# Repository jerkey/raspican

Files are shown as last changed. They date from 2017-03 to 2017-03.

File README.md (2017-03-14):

# raspican
##raspberry pi CANbus hardware in kicad
schematic
board
README.md for raspican Hardware
Files .pro .sch and .kicad_pcb in KiCAD format
License CC BY-SA 3.0
raspican Hardware

how to setup cansend software on the raspberry pi:
-------------------------------------------------
http://skpang.co.uk/blog/archives/1165

_Inspired by retired PICAN project at:_

http://skpang.co.uk/catalog/pican-canbus-board-retired-replacement-available-p-1196.html

````
22:54 < jerkey_> http://www.cowfishstudios.com/blog/canned-pi-part1
23:25 <@amatus> this stuff is out of date
23:25 <@amatus> this is what i did:
23:26 <@amatus> sudo apt-get install can-utils
23:26 <@amatus> echo dtoverlay=mcp2515-can0,oscillator=16000000,interrupt=25 >> /boot/config.txt
23:27 <@amatus> reboot
23:36 <@amatus> scratch that, echo dtoverlay=mcp2515-can0 >> /boot/config.txt
23:40 < jerkey_> https://github.com/jerkey/raspican
23:50 <@amatus> then follow the ip ... commands
Day changed to 14 Mar 2017
00:56 < jerkey_> i bet your car wasn't spitting rhymes where it was supposed to.  i can't find anything wrong with this hardware!
````

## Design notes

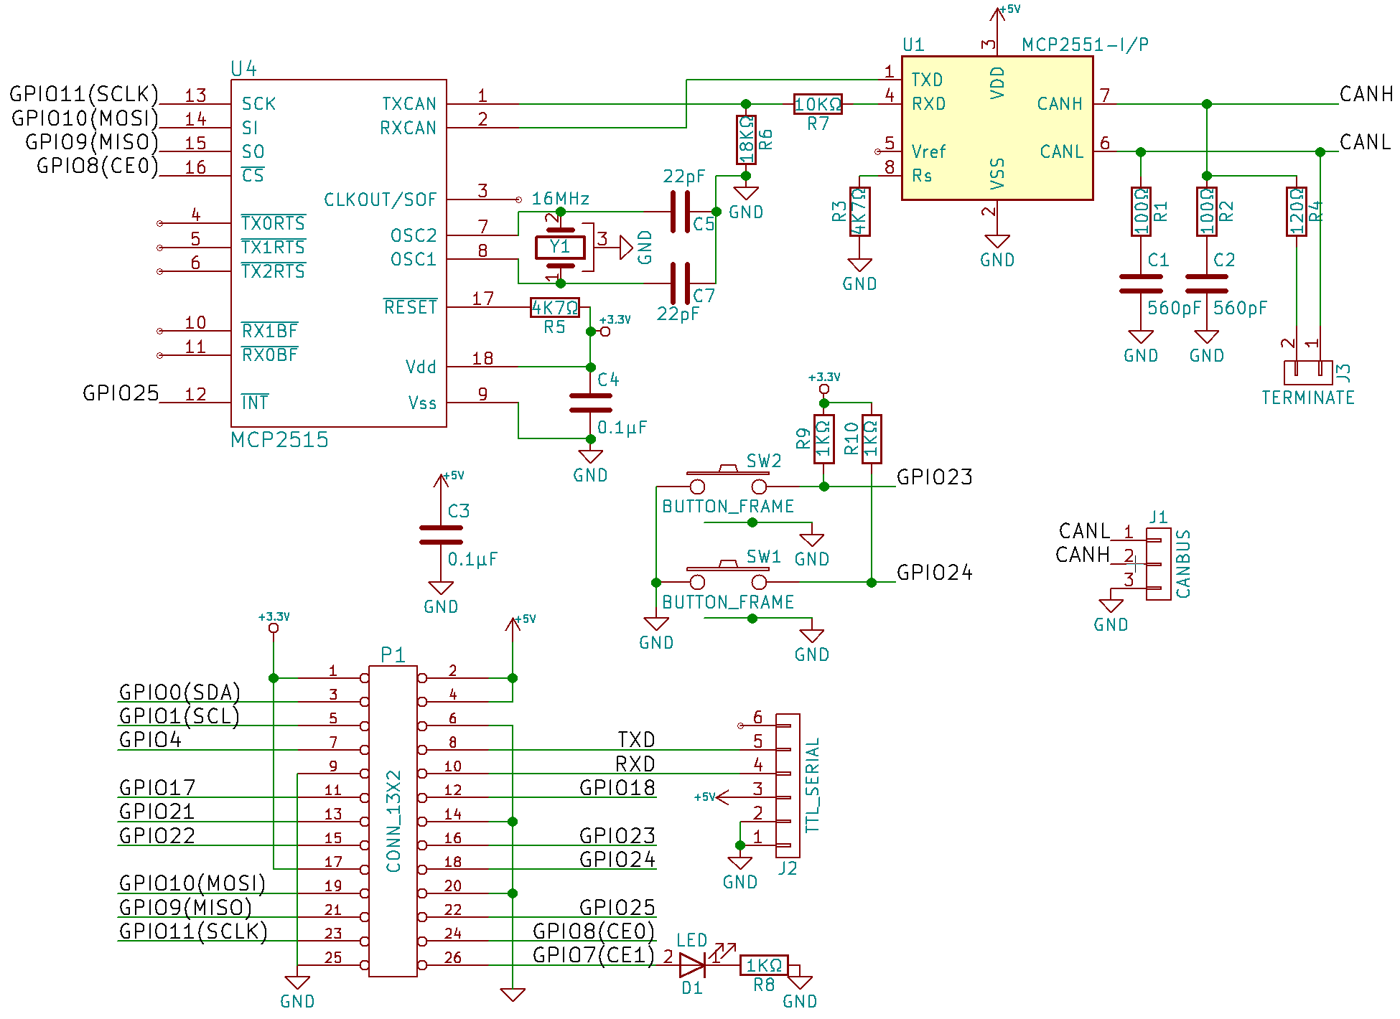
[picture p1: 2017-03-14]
schematic.png

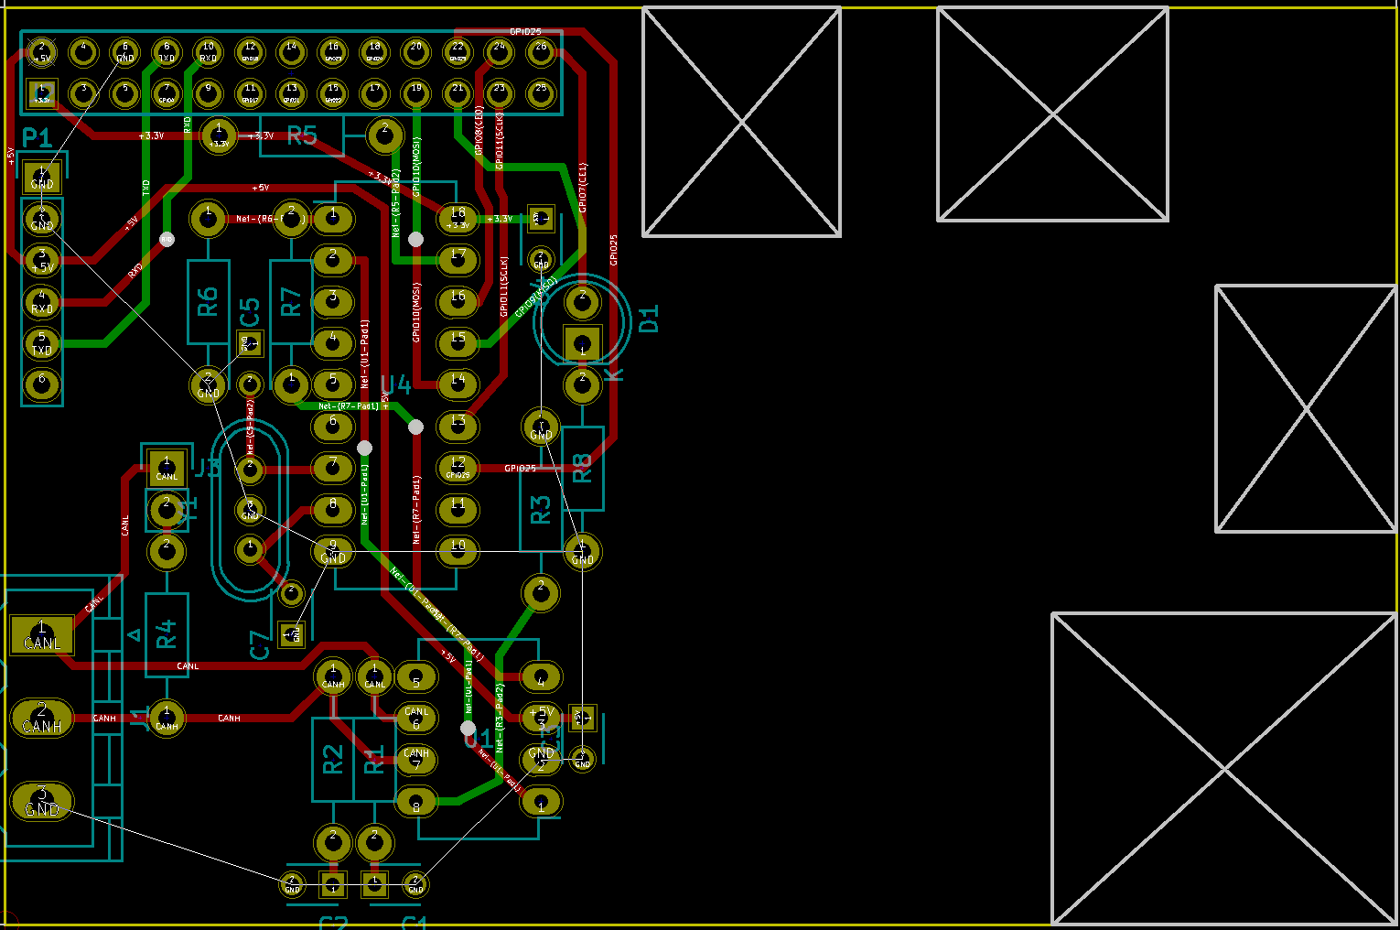
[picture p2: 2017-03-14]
board.png

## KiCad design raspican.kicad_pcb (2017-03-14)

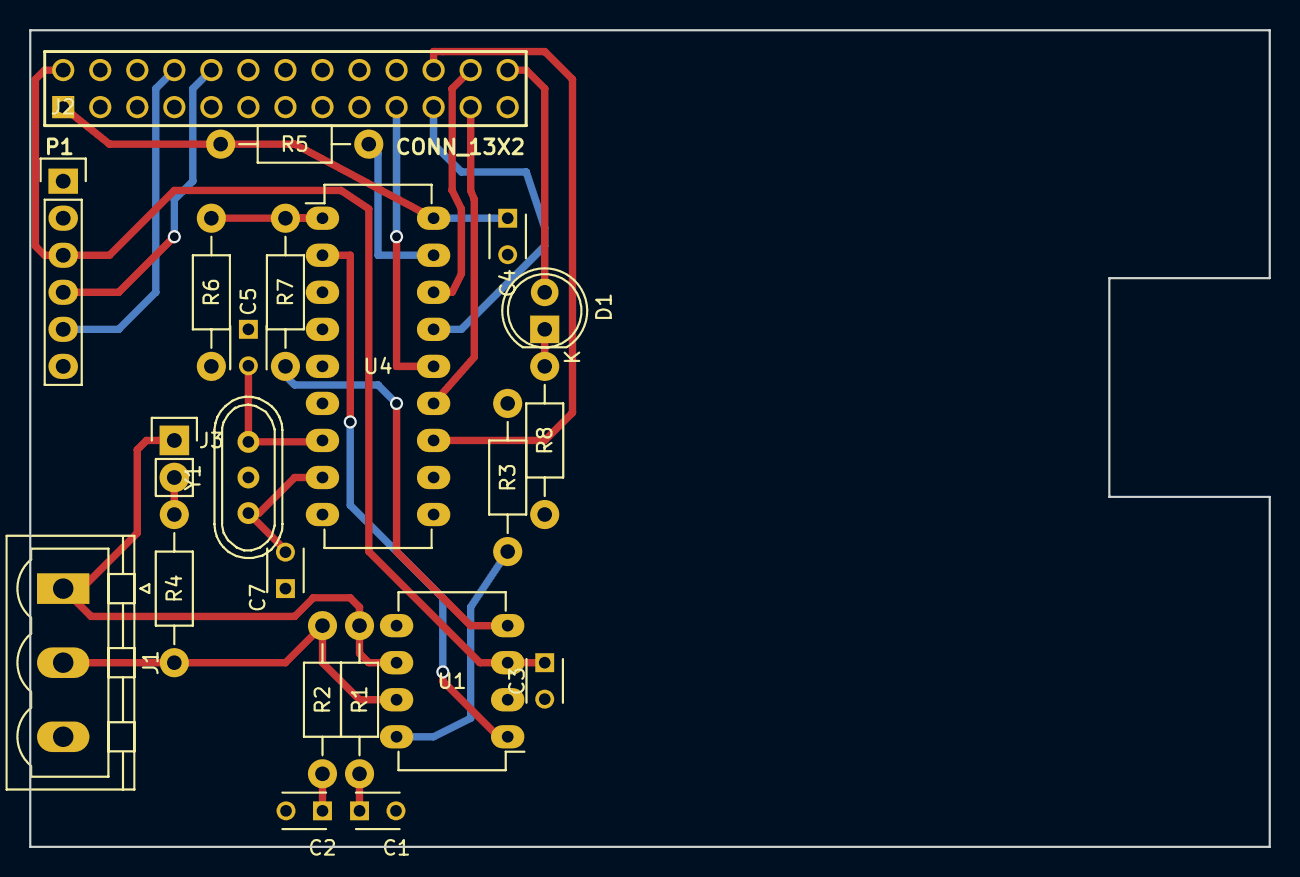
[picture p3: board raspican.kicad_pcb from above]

Board: 2 copper layers, 85.0 x 56.0 mm, 22 parts (0 on the bottom side), 24 nets.

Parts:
C1, C2: 560pF; C_Disc_D3_P2.5
C3, C4: 0.1μF; C_Disc_D3_P2.5
C5, C7: 22pF; C_Disc_D3_P2.5
D1: LED; LED-5MM
J1: CANBUS; PhoenixContact_MSTBVA-G_03x5.08mm_Vertical
J2: TTL_SERIAL; Pin_Header_Straight_1x06
J3: TERMINATE; Pin_Header_Straight_1x02
P1: CONN_13X2; pin_array_13x2
R1, R2: 100Ω; Resistor_Horizontal_RM10mm
R3, R5: 4K7Ω; Resistor_Horizontal_RM10mm
R4: 120Ω; Resistor_Horizontal_RM10mm
R6: 18KΩ; Resistor_Horizontal_RM10mm
R7: 10KΩ; Resistor_Horizontal_RM10mm
R8: 1KΩ; Resistor_Horizontal_RM10mm
U1: MCP2551-I/P; DIP-8_W7.62mm_LongPads
U4: MCP2515; DIP-18_W7.62mm_LongPads
Y1: 16MHz; Crystal_HC49-U_Vertical_3Pin

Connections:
+3.3V: C4.1, P1.1, R5.1, U4.18
+5V: C3.1, J2.3, P1.2, U1.3
/CANH: J1.2, R2.1, R4.1, U1.7
/CANL: J1.1, J3.1, R1.1, U1.6
/GPIO7(CE1): D1.2, P1.26
/GPIO8(CE0): P1.24, U4.16
/GPIO9(MISO): P1.21, U4.15
/GPIO10(MOSI): P1.19, U4.14
/GPIO11(SCLK): P1.23, U4.13
/GPIO25: P1.22, U4.12
/RXD: J2.4, P1.10
/TXD: J2.5, P1.8
GND: C1.2, C2.2, C3.2, C4.2, C5.1, C7.1, J1.3, J2.1, J2.2, P1.6, R3.1, R6.2, R8.1, U1.2, U4.9, Y1.3
unnamed: C1.1, R1.2
unnamed: C2.1, R2.2
unnamed: C5.2, U4.7, Y1.2
unnamed: C7.2, U4.8, Y1.1
unnamed: D1.1, R8.2
unnamed: J3.2, R4.2
unnamed: R3.2, U1.8
unnamed: R5.2, U4.17
unnamed: R6.1, R7.2, U4.1
unnamed: R7.1, U1.4
unnamed: U1.1, U4.2

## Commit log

2017-03-03 start wiring stuff up
    [raspican.sch]
2017-03-03 replace mcp2515 with correct DIP/SOIC pinout
    [raspican.sch]
2017-03-03 finished schematic, ready to make a board
    [raspican.sch]
2017-03-03 add schematic of original pican board for reference
2017-03-04 assign through-hole footprints to all parts
    [raspican.sch]
2017-03-04 change crystal in schematic to have ground on pin 3
    [raspican.sch]
2017-03-04 place most parts, fix grid
    [raspican.kicad_pcb]
2017-03-04 move footprints around, aligned with grid
    [raspican.kicad_pcb]
2017-03-04 add picture of the board so far
2017-03-07 add custom trace widths and start running traces
    [raspican.kicad_pcb]
2017-03-07 ok i ran all the traces except ground. and no more buttons.
    [raspican.kicad_pcb]
2017-03-14 finish running traces on the board
    [raspican.kicad_pcb]
2017-03-14 template was wrong about P1 connections
    [raspican.sch]
